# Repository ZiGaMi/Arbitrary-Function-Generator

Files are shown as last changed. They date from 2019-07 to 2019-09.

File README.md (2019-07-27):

# Arbitrary-Function-Generator
This repository contains of KiCad schematic and layout files, RTL code for iCE40 FPGA, C code for STM32F031K6 MCU and python script for software configuration of function generator.  

## Description
DAC: 12-bit R-2R ladder\
Output voltage: 3.3V\
SC current: 3.3mA

### Modes
Sinus: up to 1MHz\
Square: up to 100kHz\
Triange: up to 100kHz\
Saw: up to 100kHz\
Arbitrary: TBD

## Pics

3d_pic

work still in process...

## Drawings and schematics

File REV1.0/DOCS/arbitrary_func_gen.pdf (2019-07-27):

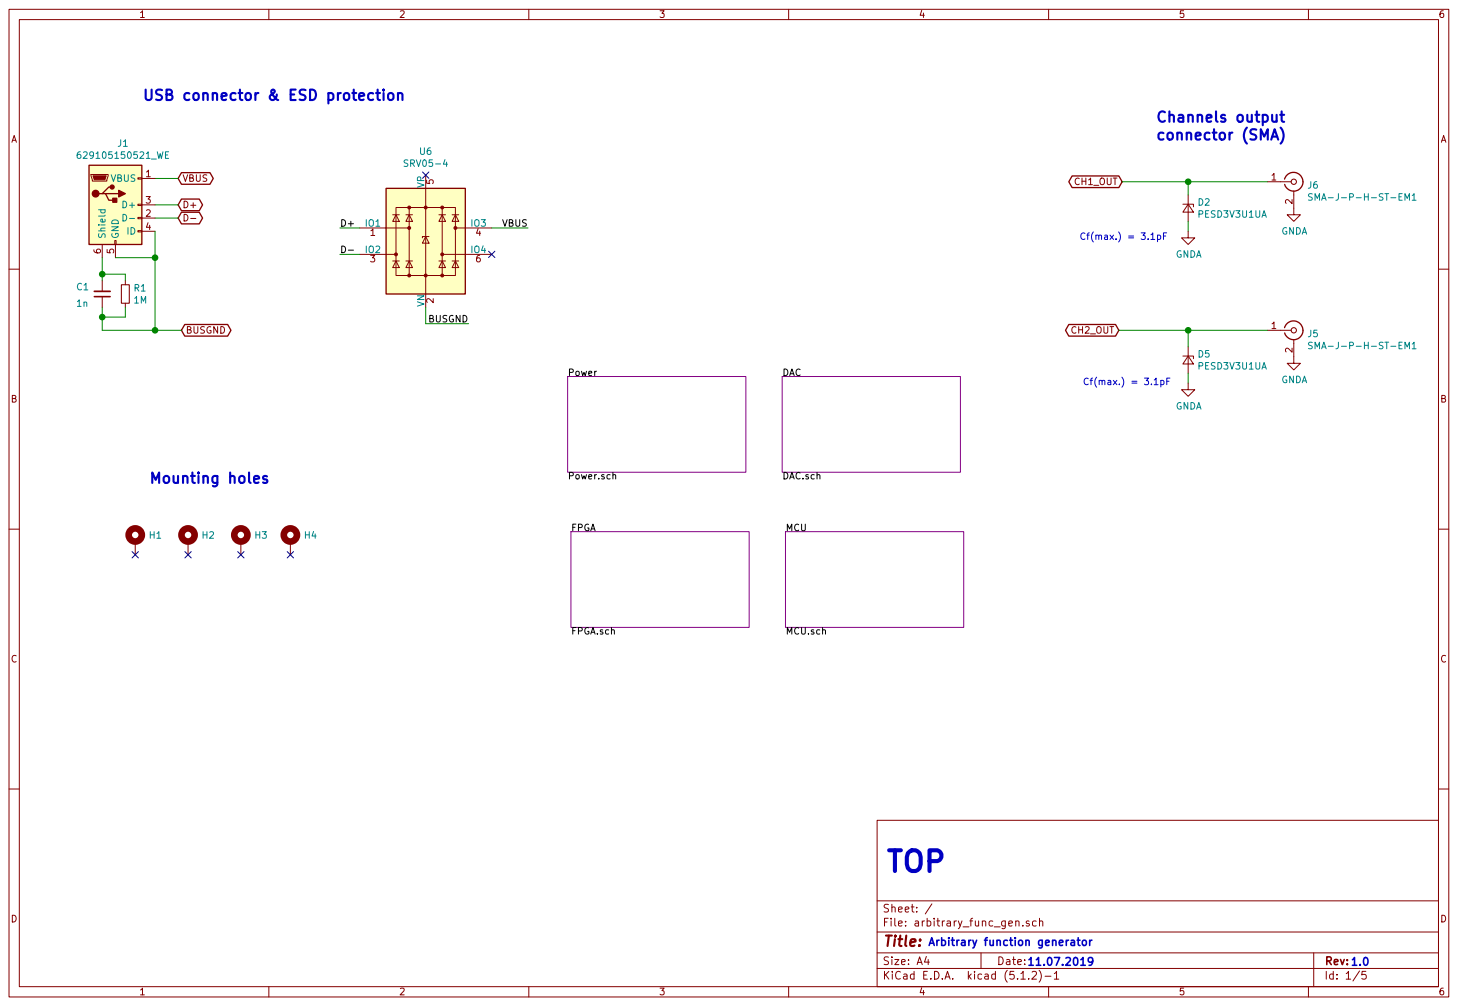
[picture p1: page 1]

J5 SMA-J-P-H-ST-EM1 GNDA D2PESD3V3U1UA GNDAD5PESD3V3U1UA GNDA Cf(max.) = 3.1pF

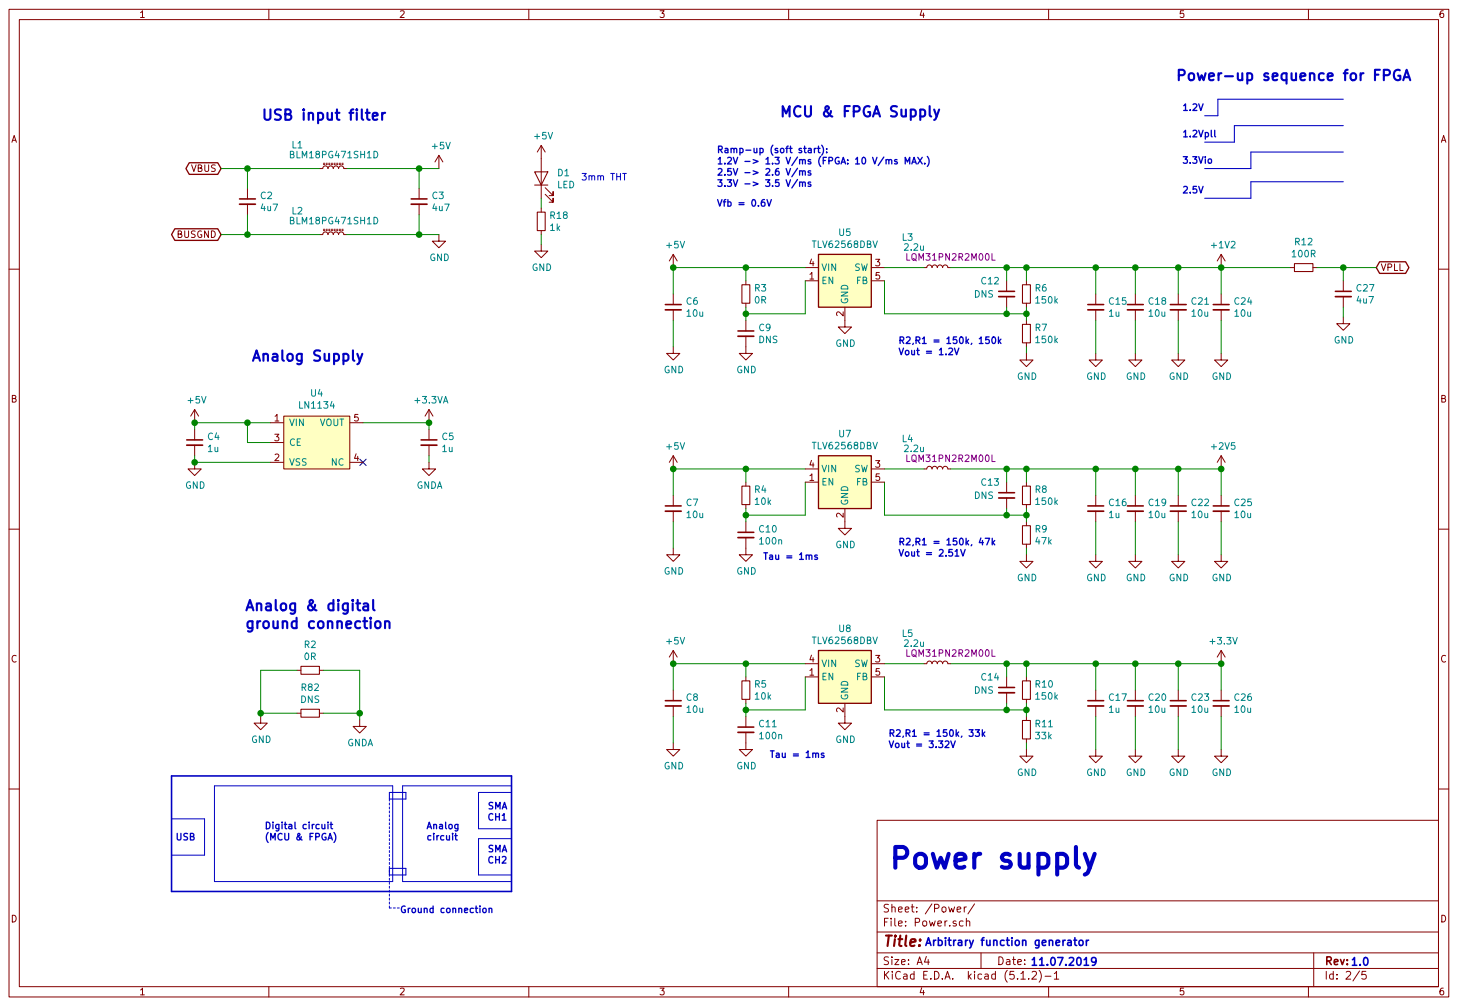
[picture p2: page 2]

Ramp-up (soft start):
1.2V -> 1.3 V/ms (FPGA: 10 V/ms MAX.) 2.5V -> 2.6 V/ms

Id: 2/5 Title: File: Power.sch Sheet: /Power/ Power supply

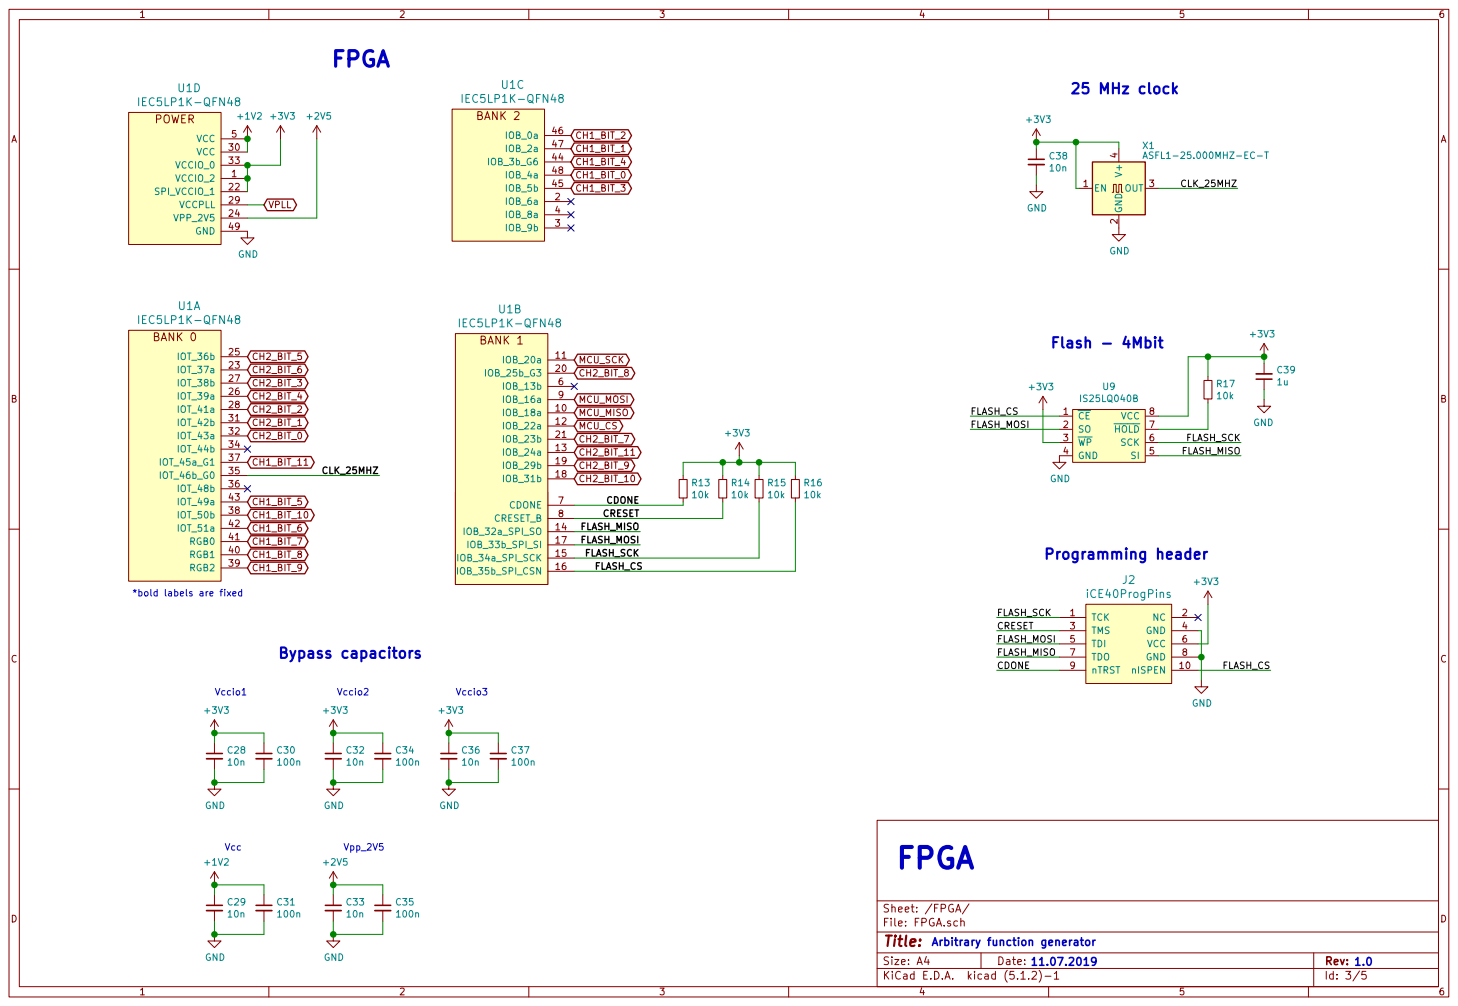
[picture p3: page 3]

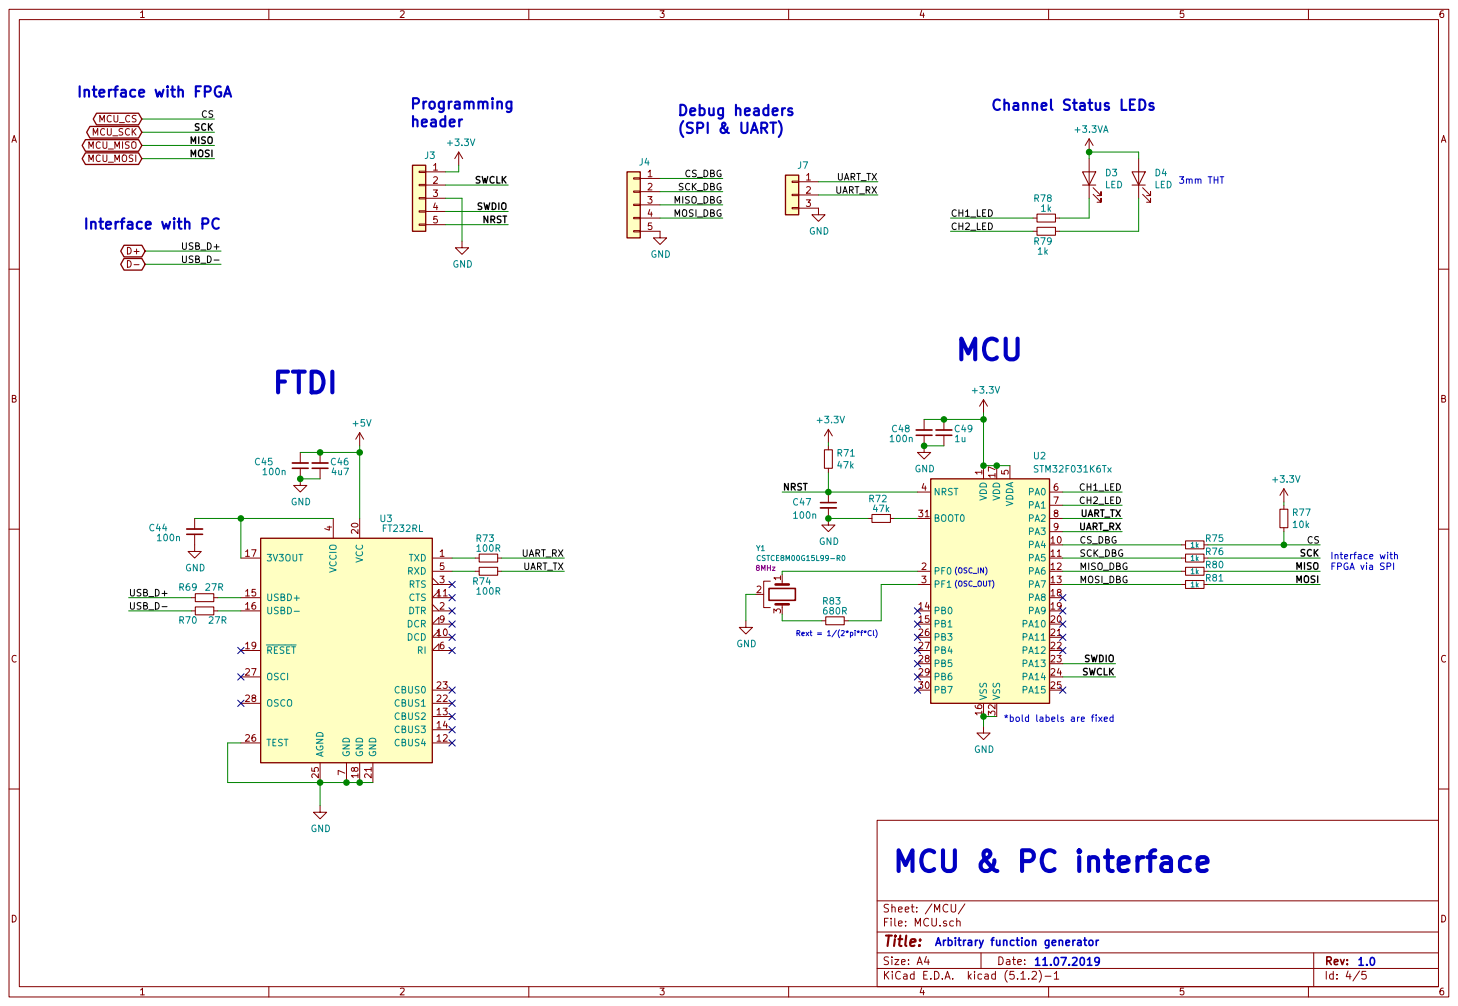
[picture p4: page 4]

SCK MISO MOSI CS MCU_SCK MCU_CS MCU_MISO MCU_MOSI Interface with FPGA

5 VSS 16 VSS 32 U2STM32F031K6Tx SCK MISO MOSI CS

Interface with FPGA via SPI

*bold labels are fixedSWDIO

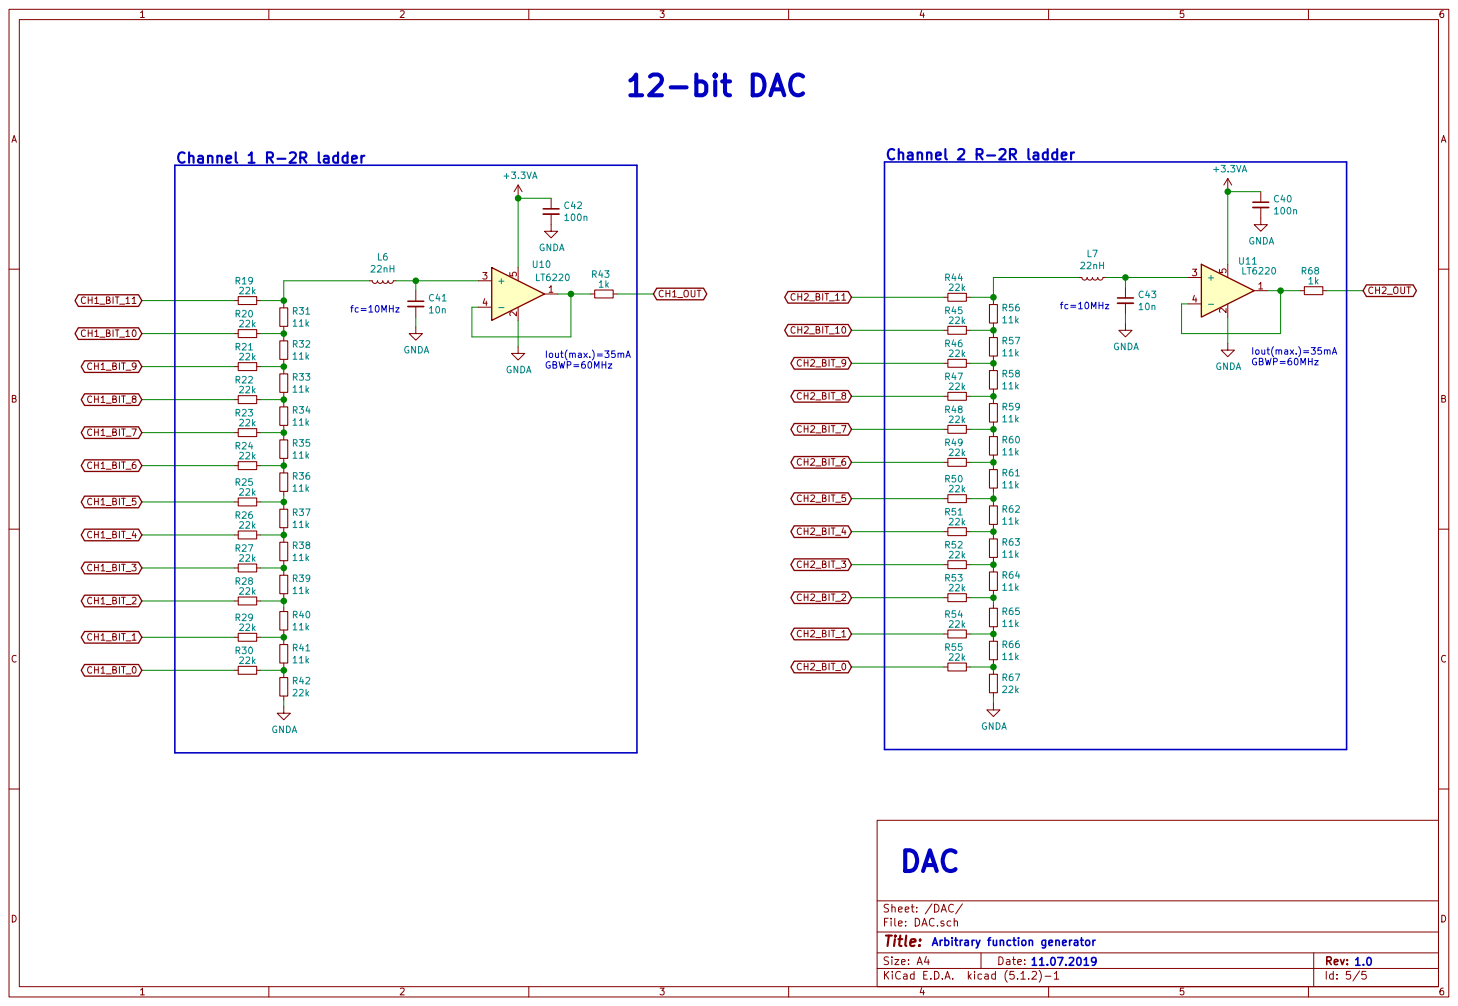
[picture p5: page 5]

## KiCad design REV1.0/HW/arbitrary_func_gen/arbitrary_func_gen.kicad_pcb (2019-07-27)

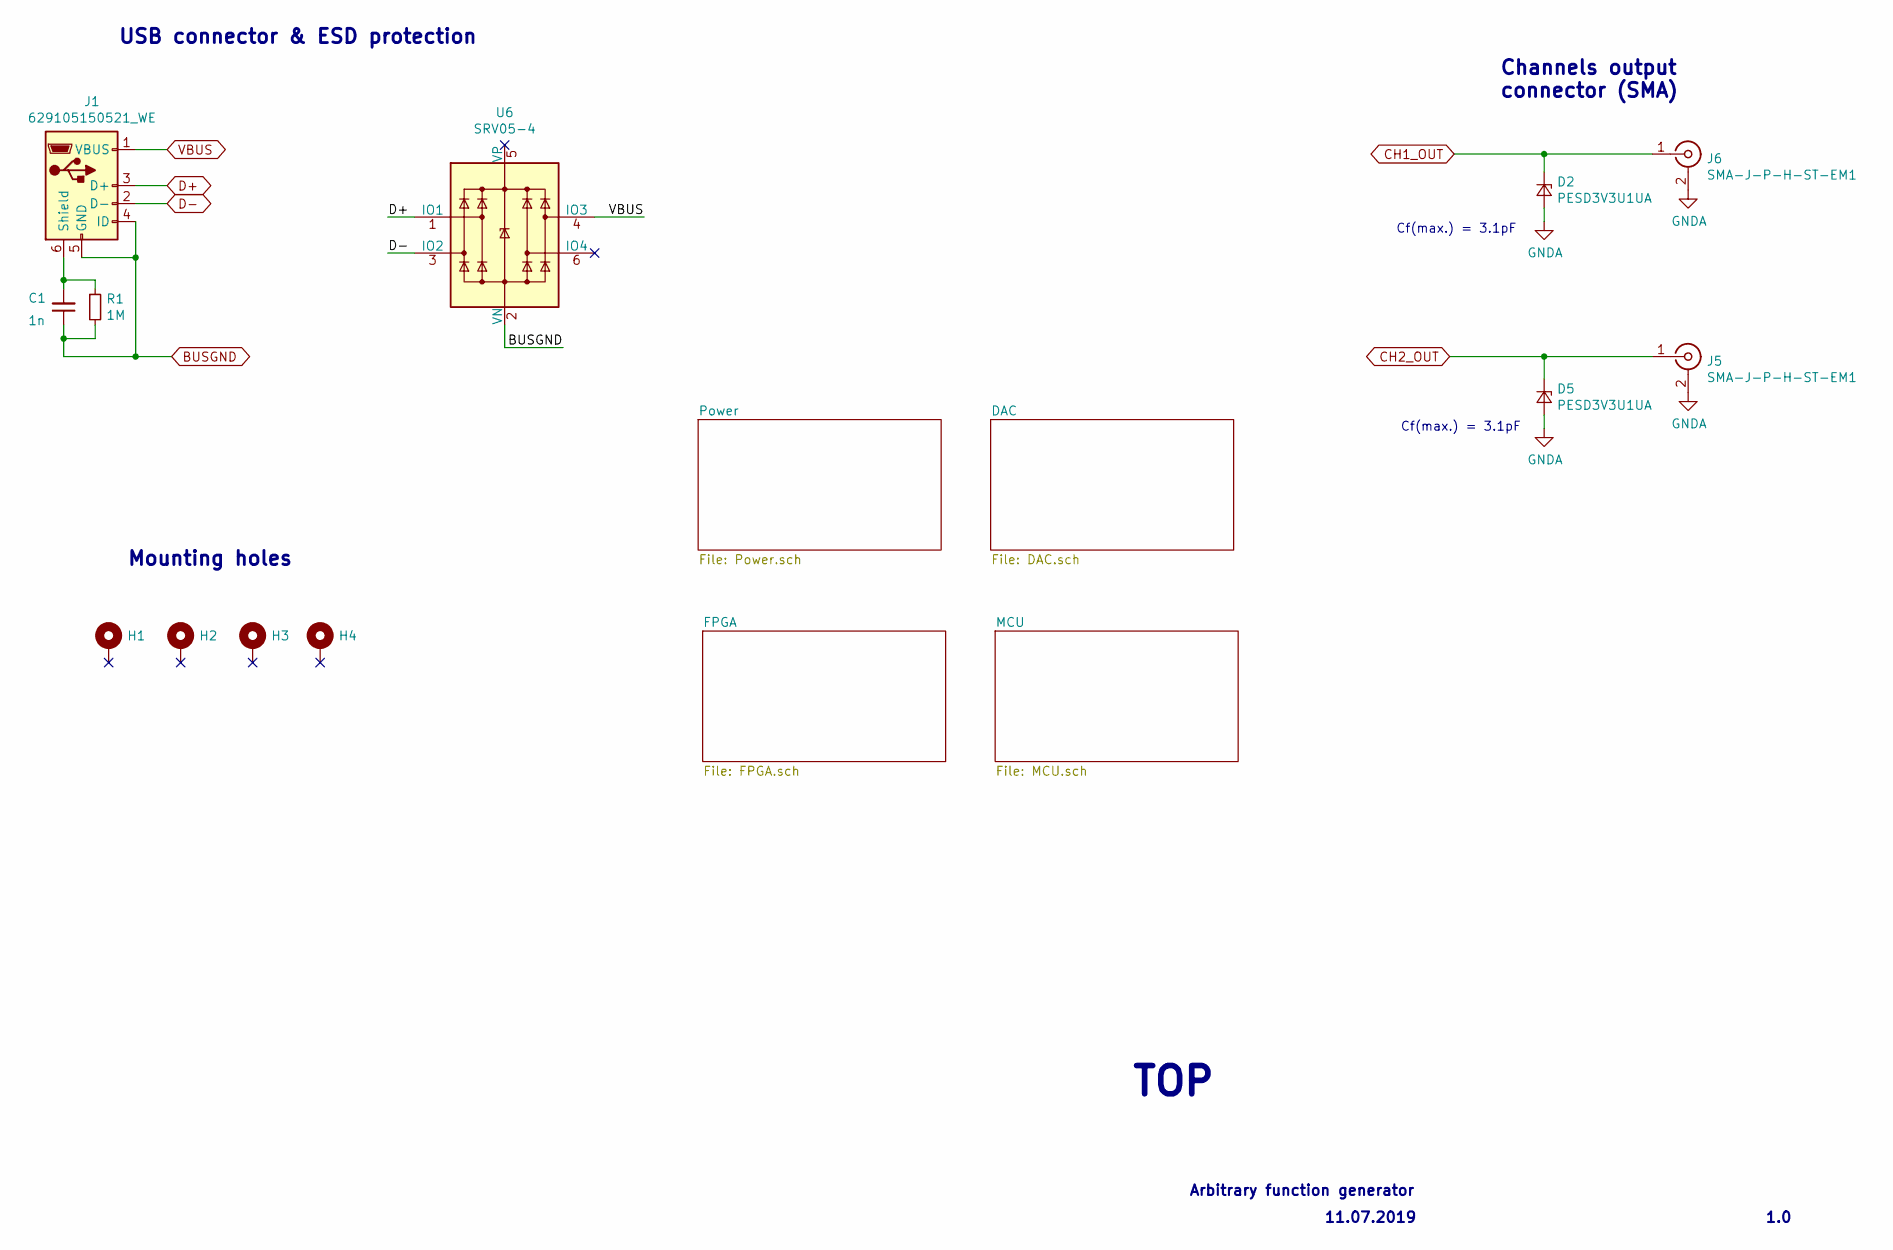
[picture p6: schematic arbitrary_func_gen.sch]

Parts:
C1: 1n; C_0603_HandSoldering
D2, D5: PESD3V3U1UA; D_SOD-323_HandSoldering
H1, H2, H3, H4: MountingHole_3.2mm_M3_Pad
J1: 629105150521_WE; USBMicro_629105150521_WE
J5, J6: SMA-J-P-H-ST-EM1; SMA_Coaxsial_EdgeBoard_Connector
R1: 1M; R_0603_HandSoldering
U6: SRV05-4; SOT-23-6_Handsoldering

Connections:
BUSGND: C1.1, J1.4 (ID), J1.5 (GND), R1.2, U6.2 (VN); also elsewhere on the board
CH1_OUT: D2.1 (K), J6.1 (In); also elsewhere on the board
CH2_OUT: D5.1 (K), J5.1 (In); also elsewhere on the board
D+: J1.3 (D+), U6.1 (IO1); also elsewhere on the board
D-: J1.2 (D-), U6.3 (IO2); also elsewhere on the board
GNDA: D2.2 (A), D5.2 (A), J5.2 (Ext), J6.2 (Ext); also elsewhere on the board
unnamed: C1.2, J1.6 (Shield), R1.1
VBUS: J1.1 (VBUS), U6.4 (IO3); also elsewhere on the board

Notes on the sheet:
TOP
11.07.2019
1.0
Arbitrary function generator
USB connector & ESD protection
Mounting holes
Channels output connector (SMA)
Cf(max.) = 3.1pF

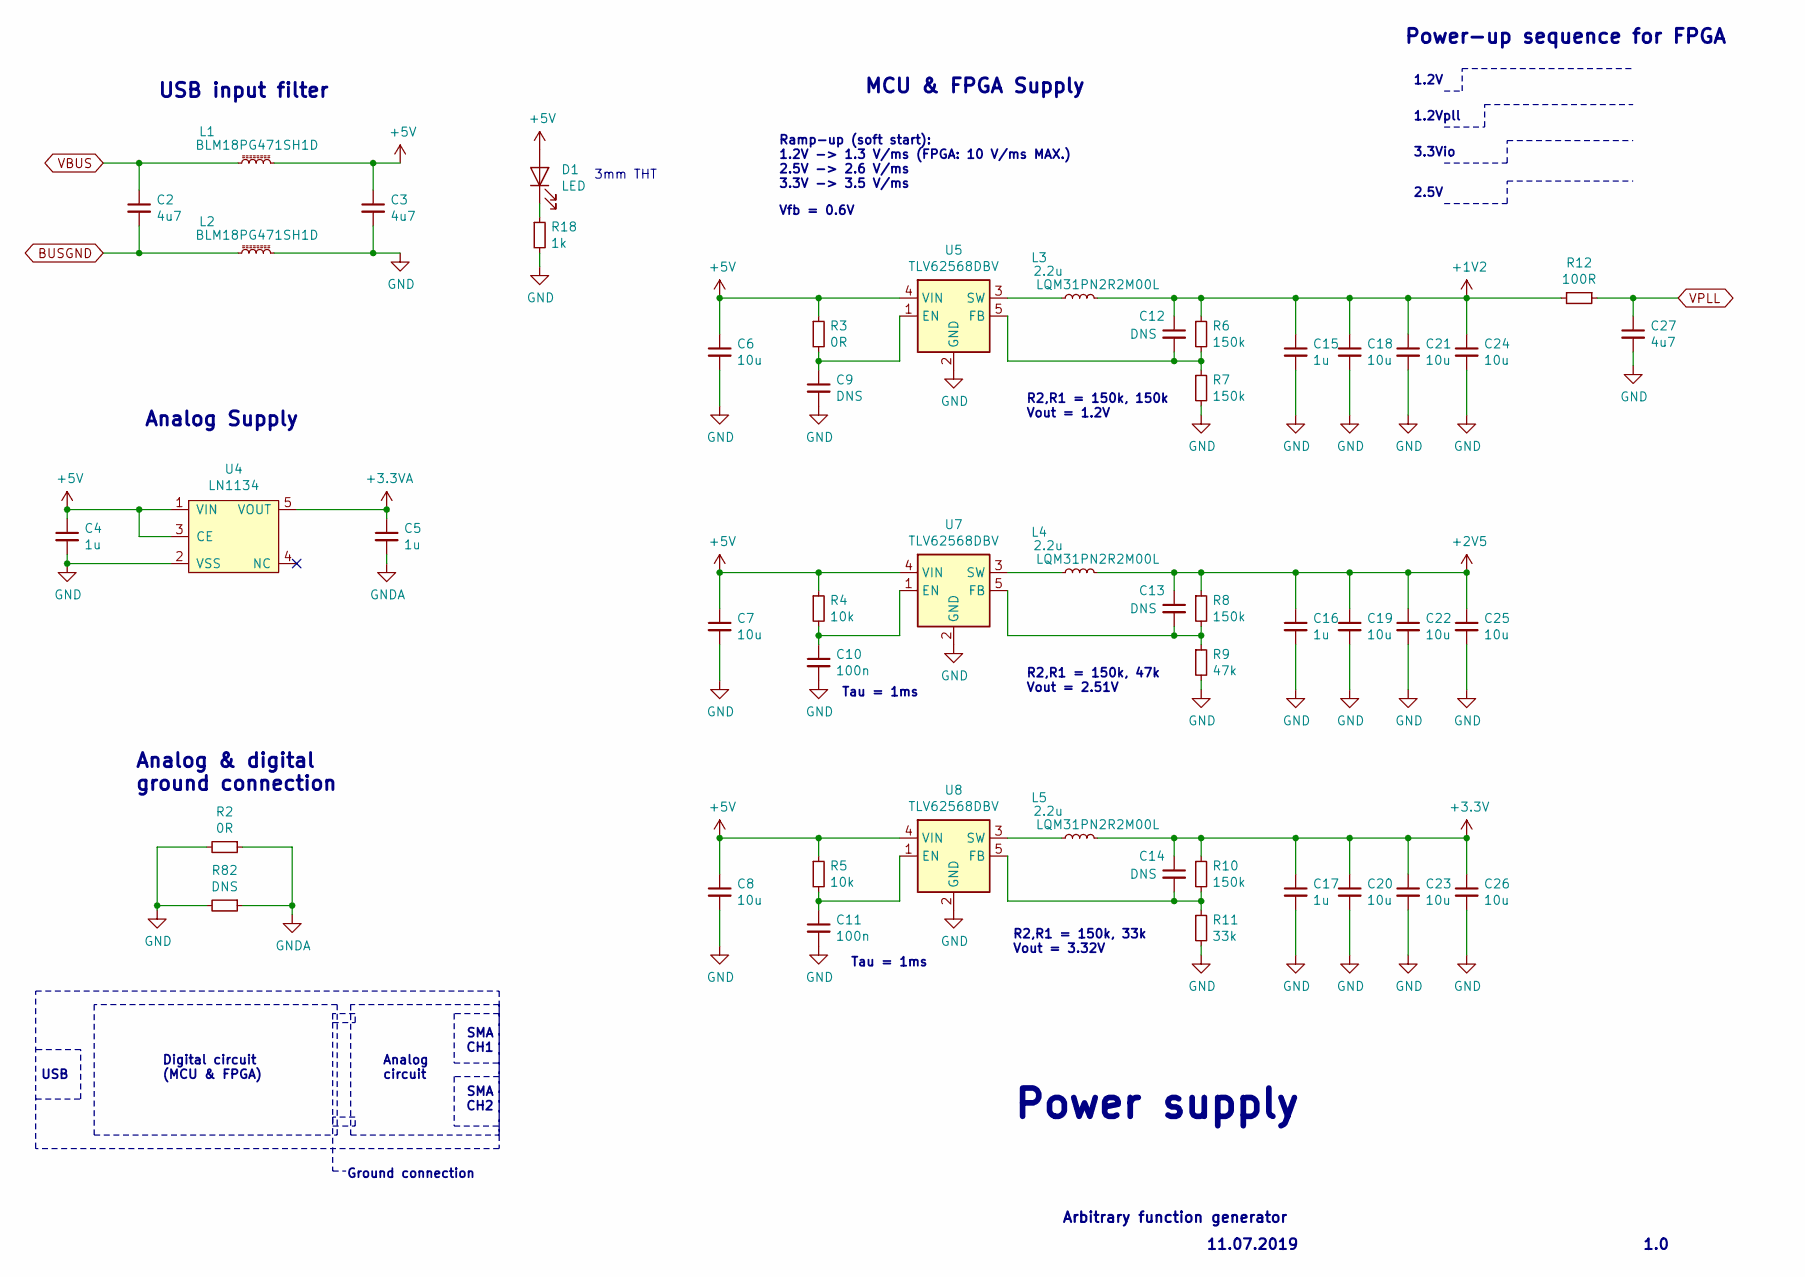
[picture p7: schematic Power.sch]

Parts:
C2, C3, C27: 4u7; C_0805_HandSoldering
C4, C5, C15, C16, C17: 1u; C_0603_HandSoldering
C6, C7, C8, C18, C19, C20, C21, C22, C23, C24, C25, C26: 10u; C_0805_HandSoldering
C9, C12, C13, C14: DNS; C_0603_HandSoldering
C10, C11: 100n; C_0603_HandSoldering
D1: LED; LED_D3.0mm_FlatTop
L1, L2: BLM18PG471SH1D; L_0603_HandSoldering
L3, L4, L5: 2.2u; L_1206_HandSoldering
R2: 0R; R_1206_HandSoldering
R3: 0R; R_0603_HandSoldering
R4, R5: 10k; R_0603_HandSoldering
R6, R7, R8, R10: 150k; R_0603_HandSoldering
R9: 47k; R_0603_HandSoldering
R11: 33k; R_0603_HandSoldering
R12: 100R; R_0603_HandSoldering
R18: 1k; R_0603_HandSoldering
R82: DNS; R_1206_HandSoldering
U4: LN1134; SOT-23-5_HandSoldering
U5, U7, U8: TLV62568DBV; SOT-23-5_HandSoldering

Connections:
+1V2: C12.1, C15.1, C18.1, C21.1, C24.1, L3.2, R6.1, R12.2; also elsewhere on the board
+2V5: C13.1, C16.1, C19.1, C22.1, C25.1, L4.2, R8.1; also elsewhere on the board
+3.3VA: C5.1, U4.5 (VOUT); also elsewhere on the board
+5V: C3.1, C4.1, C6.1, C7.1, C8.1, D1.2 (A), L1.2, R3.1, R4.1, R5.1, U4.1 (VIN), U4.3 (CE), U5.4 (VIN), U7.4 (VIN), U8.4 (VIN); also elsewhere on the board
BUSGND: C2.2, L2.1; also elsewhere on the board
GND: C3.2, C4.2, C6.2, C7.2, C8.2, C9.2, C10.2, C11.2, C15.2, C16.2, C17.2, C18.2, C19.2, C20.2, C21.2, C22.2, C23.2, C24.2, C25.2, C26.2, C27.2, L2.2, R2.2, R7.2, R9.2, R11.2, R18.2, R82.2, U4.2 (VSS), U5.2 (GND), U7.2 (GND), U8.2 (GND); also elsewhere on the board
GNDA: C5.2, R2.1, R82.1; also elsewhere on the board
unnamed: C9.1, R3.2, U5.1 (EN)
unnamed: C10.1, R4.2, U7.1 (EN)
unnamed: C11.1, R5.2, U8.1 (EN)
unnamed: C12.2, R6.2, R7.1, U5.5 (FB)
unnamed: C13.2, R8.2, R9.1, U7.5 (FB)
unnamed: C14.2, R10.2, R11.1, U8.5 (FB)
unnamed: D1.1 (K), R18.1
unnamed: L3.1, U5.3 (SW)
unnamed: L4.1, U7.3 (SW)
unnamed: L5.1, U8.3 (SW)
VBUS: C2.1, L1.1; also elsewhere on the board
VPLL: C27.1, R12.1; also elsewhere on the board

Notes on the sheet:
Power supply
Arbitrary function generator
11.07.2019
1.0
USB input filter
Power-up sequence for FPGA
1.2V
1.2Vpll
3.3Vio
2.5V
MCU & FPGA Supply
Analog Supply
Analog & digital ground connection
Analog circuit
Digital circuit (MCU & FPGA)
USB
SMA CH2
SMA CH1
Ground connection
Ramp-up (soft start): 1.2V -> 1.3 V/ms (FPGA: 10 V/ms MAX.) 2.5V -> 2.6 V/ms 3.3V -> 3.5 V/ms
Vfb = 0.6V
R2,R1 = 150k, 33k Vout = 3.32V
R2,R1 = 150k, 47k Vout = 2.51V
R2,R1 = 150k, 150k Vout = 1.2V
Tau = 1ms
3mm THT

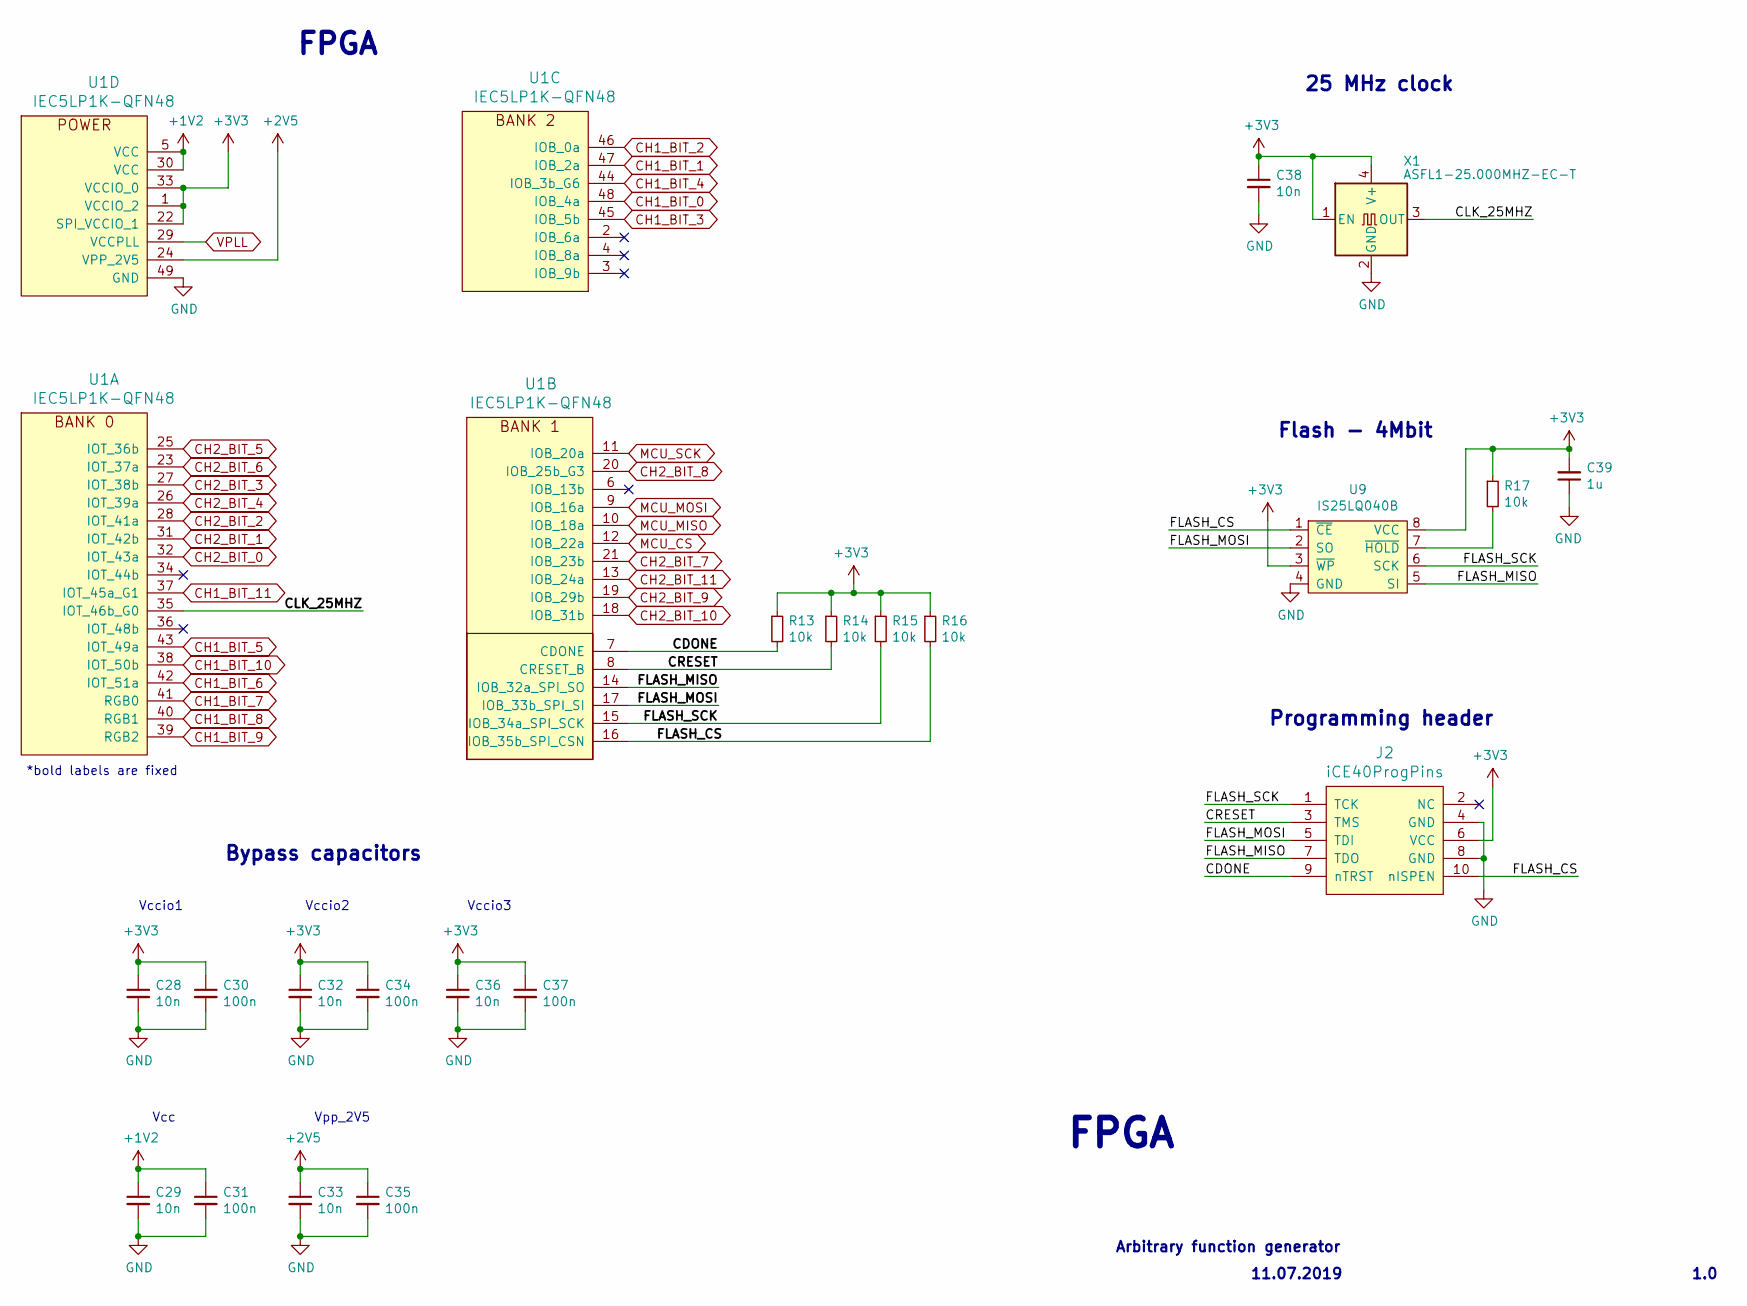
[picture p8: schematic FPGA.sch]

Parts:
C28, C29, C32, C33, C36, C38: 10n; C_0603_HandSoldering
C30, C31, C34, C35, C37: 100n; C_0603_HandSoldering
C39: 1u; C_0603_HandSoldering
J2: iCE40ProgPins; 2x5pin-R1.27mm
R13, R14, R15, R16, R17: 10k; R_0603_HandSoldering
U1: IEC5LP1K-QFN48; QFP-48_7x7_Pitch0.5mm
U9: IS25LQ040B; SOIC-8_3.9x4.9mm_Pitch1.27mm
X1: ASFL1-25.000MHZ-EC-T; Oscillator_SMD_Abracon_ASE-4pin_3.2x2.5mm_HandSoldering

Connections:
+1V2: C29.1, C31.1, U1.5 (VCC), U1.30 (VCC); also elsewhere on the board
+2V5: C33.1, C35.1, U1.24 (VPP_2V5); also elsewhere on the board
/FPGA/CDONE: J2.9 (nTRST), R13.2, U1.7 (CDONE)
/FPGA/CLK_25MHZ: U1.35 (IOT_46b_G0), X1.3 (OUT)
/FPGA/CRESET: J2.3 (TMS), R14.2, U1.8 (CRESET_B)
/FPGA/FLASH_CS: J2.10 (nISPEN), R16.2, U1.16 (IOB_35b_SPI_CSN), U9.1 (~CE)
/FPGA/FLASH_MISO: J2.7 (TDO), U1.14 (IOB_32a_SPI_SO), U9.5 (SI)
/FPGA/FLASH_MOSI: J2.5 (TDI), U1.17 (IOB_33b_SPI_SI), U9.2 (SO)
/FPGA/FLASH_SCK: J2.1 (TCK), R15.2, U1.15 (IOB_34a_SPI_SCK), U9.6 (SCK)
CH1_BIT_0: U1.48 (IOB_4a); also elsewhere on the board
CH1_BIT_1: U1.47 (IOB_2a); also elsewhere on the board
CH1_BIT_2: U1.46 (IOB_0a); also elsewhere on the board
CH1_BIT_3: U1.45 (IOB_5b); also elsewhere on the board
CH1_BIT_4: U1.44 (IOB_3b_G6); also elsewhere on the board
CH1_BIT_5: U1.43 (IOT_49a); also elsewhere on the board
CH1_BIT_6: U1.42 (IOT_51a); also elsewhere on the board
CH1_BIT_7: U1.41 (RGB0); also elsewhere on the board
CH1_BIT_8: U1.40 (RGB1); also elsewhere on the board
CH1_BIT_9: U1.39 (RGB2); also elsewhere on the board
CH1_BIT_10: U1.38 (IOT_50b); also elsewhere on the board
CH1_BIT_11: U1.37 (IOT_45a_G1); also elsewhere on the board
CH2_BIT_0: U1.32 (IOT_43a); also elsewhere on the board
CH2_BIT_1: U1.31 (IOT_42b); also elsewhere on the board
CH2_BIT_2: U1.28 (IOT_41a); also elsewhere on the board
CH2_BIT_3: U1.27 (IOT_38b); also elsewhere on the board
CH2_BIT_4: U1.26 (IOT_39a); also elsewhere on the board
CH2_BIT_5: U1.25 (IOT_36b); also elsewhere on the board
CH2_BIT_6: U1.23 (IOT_37a); also elsewhere on the board
CH2_BIT_7: U1.21 (IOB_23b); also elsewhere on the board
CH2_BIT_8: U1.20 (IOB_25b_G3); also elsewhere on the board
CH2_BIT_9: U1.19 (IOB_29b); also elsewhere on the board
CH2_BIT_10: U1.18 (IOB_31b); also elsewhere on the board
CH2_BIT_11: U1.13 (IOB_24a); also elsewhere on the board
GND: C28.2, C29.2, C30.2, C31.2, C32.2, C33.2, C34.2, C35.2, C36.2, C37.2, C38.2, C39.1, J2.4 (GND), J2.8 (GND), U1.49 (GND), U9.4 (GND), X1.2 (GND); also elsewhere on the board
MCU_CS: U1.12 (IOB_22a); also elsewhere on the board
MCU_MISO: U1.10 (IOB_18a); also elsewhere on the board
MCU_MOSI: U1.9 (IOB_16a); also elsewhere on the board
MCU_SCK: U1.11 (IOB_20a); also elsewhere on the board
unnamed: R17.2, U9.7 (~HOLD)
VPLL: U1.29 (VCCPLL); also elsewhere on the board

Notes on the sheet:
11.07.2019
1.0
Arbitrary function generator
FPGA
*bold labels are fixed
Vccio1
Vccio2
Vccio3
Vcc
Vpp_2V5
Bypass capacitors
25 MHz clock
Flash - 4Mbit
Programming header

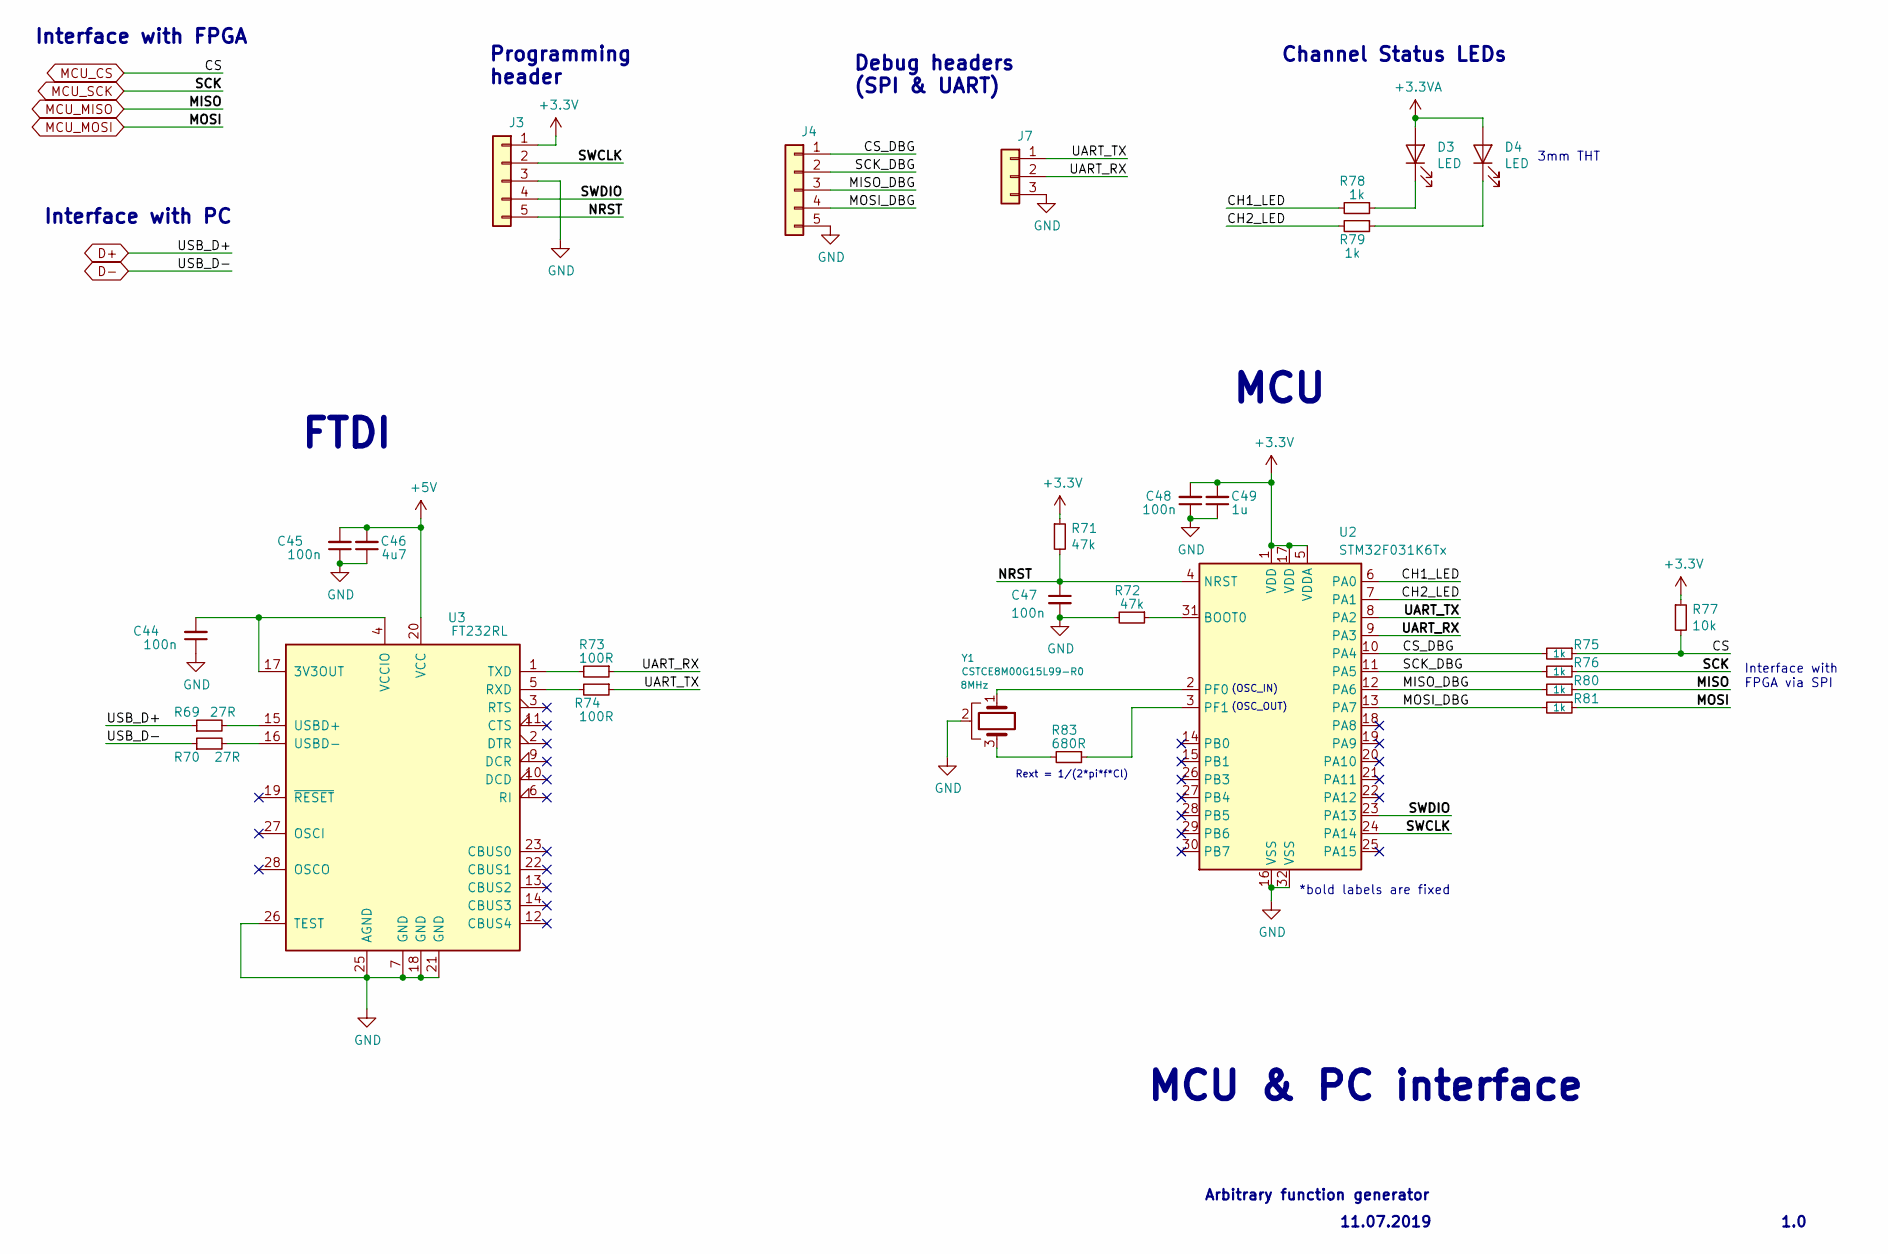
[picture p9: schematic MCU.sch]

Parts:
C44, C45, C47, C48: 100n; C_0603_HandSoldering
C46: 4u7; C_0805_HandSoldering
C49: 1u; C_0603_HandSoldering
D3, D4: LED; LED_D3.0mm_FlatTop
J3, J4: Conn_01x05; Pin_Header_Straight_1x05_Pitch2.54mm
J7: Conn_01x03; Pin_Header_Straight_1x03_Pitch2.54mm
R69, R70: 27R; R_0603_HandSoldering
R71, R72: 47k; R_0603_HandSoldering
R73, R74: 100R; R_0603_HandSoldering
R75, R76, R78, R79, R80, R81: 1k; R_0603_HandSoldering
R77: 10k; R_0603_HandSoldering
R83: 680R; R_0603_HandSoldering
U2: STM32F031K6Tx; LQFP-32_7x7mm_Pitch0.8mm
U3: FT232RL; SSOP-28_5.3x10.2mm_Pitch0.65mm
Y1: CSTCE8M00G15L99-R0; Crystal_Murata3Pin

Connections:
+3.3VA: D3.2 (A), D4.2 (A); also elsewhere on the board
+5V: C45.2, C46.2, U3.20 (VCC); also elsewhere on the board
/MCU/CH1_LED: R78.2, U2.6 (PA0)
/MCU/CH2_LED: R79.2, U2.7 (PA1)
/MCU/CS_DBG: J4.1, R75.2, U2.10 (PA4)
/MCU/MISO_DBG: J4.3, R80.2, U2.12 (PA6)
/MCU/MOSI_DBG: J4.4, R81.2, U2.13 (PA7)
/MCU/NRST: C47.1, J3.5, R71.2, U2.4 (NRST)
/MCU/SCK_DBG: J4.2, R76.2, U2.11 (PA5)
/MCU/SWCLK: J3.2, U2.24 (PA14)
/MCU/SWDIO: J3.4, U2.23 (PA13)
/MCU/UART_RX: J7.2, R73.1, U2.9 (PA3)
/MCU/UART_TX: J7.1, R74.1, U2.8 (PA2)
D+: R69.1; also elsewhere on the board
D-: R70.1; also elsewhere on the board
GND: C44.1, C45.1, C46.1, C47.2, C48.1, C49.1, J3.3, J4.5, J7.3, R72.2, U2.16 (VSS), U2.32 (VSS), U3.7 (GND), U3.18 (GND), U3.21 (GND), U3.25 (AGND), U3.26 (TEST), Y1.2; also elsewhere on the board
MCU_CS: R75.1, R77.2; also elsewhere on the board
MCU_MISO: R80.1; also elsewhere on the board
MCU_MOSI: R81.1; also elsewhere on the board
MCU_SCK: R76.1; also elsewhere on the board
unnamed: C44.2, U3.4 (VCCIO), U3.17 (3V3OUT)
unnamed: D3.1 (K), R78.1
unnamed: D4.1 (K), R79.1
unnamed: R69.2, U3.15 (USBD+)
unnamed: R70.2, U3.16 (USBD-)
unnamed: R72.1, U2.31 (BOOT0)
unnamed: R73.2, U3.1 (TXD)
unnamed: R74.2, U3.5 (RXD)
unnamed: R83.1, U2.3 (PF1)
unnamed: R83.2, Y1.3
unnamed: U2.2 (PF0), Y1.1

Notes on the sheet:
11.07.2019
1.0
Arbitrary function generator
MCU & PC interface
*bold labels are fixed
Programming header
Interface with FPGA via SPI
Interface with FPGA
Interface with PC
Debug headers (SPI & UART)
Channel Status LEDs
3mm THT
MCU
FTDI
(OSC_IN)
(OSC_OUT)
Rext = 1/(2*pi*f*Cl)

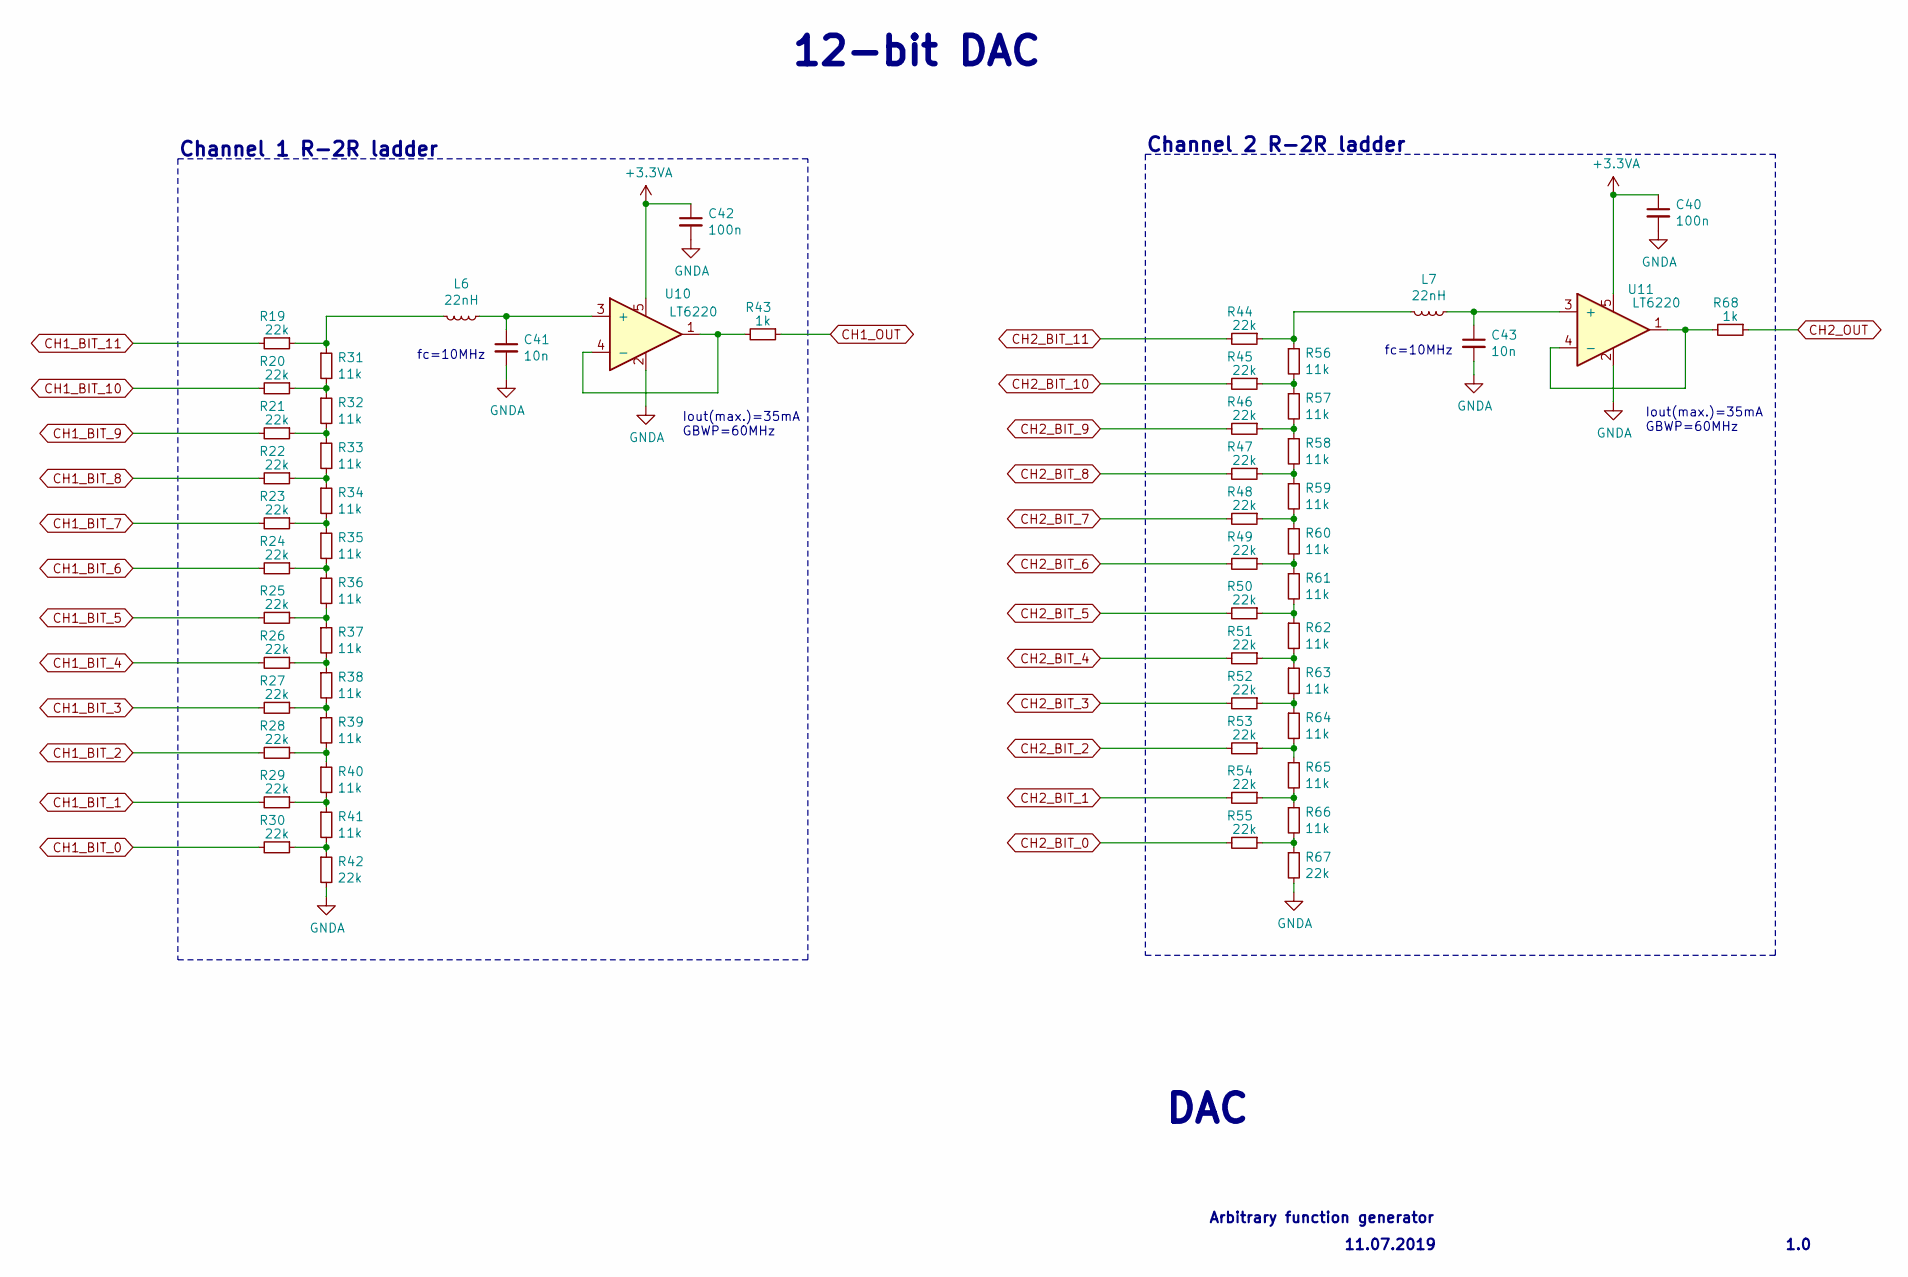
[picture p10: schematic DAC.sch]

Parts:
C40, C42: 100n; C_0603_HandSoldering
C41, C43: 10n; C_0603_HandSoldering
L6, L7: 22nH; L_0603_HandSoldering
R19, R20, R21, R22, R23, R24, R25, R26, R27, R28, R29, R30, R42, R44, R45, R46, R47, R48, R49, R50, R51, R52, R53, R54, R55, R67: 22k; R_0603_HandSoldering
R31, R32, R33, R34, R35, R36, R37, R38, R39, R40, R41, R56, R57, R58, R59, R60, R61, R62, R63, R64, R65, R66: 11k; R_0603_HandSoldering
R43, R68: 1k; R_0603_HandSoldering
U10, U11: LT6220; SOT-23-5_HandSoldering

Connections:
+3.3VA: C40.1, C42.1, U10.5, U11.5; also elsewhere on the board
CH1_BIT_0: R30.2; also elsewhere on the board
CH1_BIT_1: R29.2; also elsewhere on the board
CH1_BIT_2: R28.2; also elsewhere on the board
CH1_BIT_3: R27.2; also elsewhere on the board
CH1_BIT_4: R26.2; also elsewhere on the board
CH1_BIT_5: R25.2; also elsewhere on the board
CH1_BIT_6: R24.2; also elsewhere on the board
CH1_BIT_7: R23.2; also elsewhere on the board
CH1_BIT_8: R22.2; also elsewhere on the board
CH1_BIT_9: R21.2; also elsewhere on the board
CH1_BIT_10: R20.2; also elsewhere on the board
CH1_BIT_11: R19.2; also elsewhere on the board
CH1_OUT: R43.1; also elsewhere on the board
CH2_BIT_0: R55.2; also elsewhere on the board
CH2_BIT_1: R54.2; also elsewhere on the board
CH2_BIT_2: R53.2; also elsewhere on the board
CH2_BIT_3: R52.2; also elsewhere on the board
CH2_BIT_4: R51.2; also elsewhere on the board
CH2_BIT_5: R50.2; also elsewhere on the board
CH2_BIT_6: R49.2; also elsewhere on the board
CH2_BIT_7: R48.2; also elsewhere on the board
CH2_BIT_8: R47.2; also elsewhere on the board
CH2_BIT_9: R46.2; also elsewhere on the board
CH2_BIT_10: R45.2; also elsewhere on the board
CH2_BIT_11: R44.2; also elsewhere on the board
CH2_OUT: R68.1; also elsewhere on the board
GNDA: C40.2, C41.2, C42.2, C43.2, R42.2, R67.2, U10.2, U11.2; also elsewhere on the board
unnamed: C41.1, L6.1, U10.3 (+)
unnamed: C43.1, L7.1, U11.3 (+)
unnamed: L6.2, R19.1, R31.1
unnamed: L7.2, R44.1, R56.1
unnamed: R20.1, R31.2, R32.1
unnamed: R21.1, R32.2, R33.1
unnamed: R22.1, R33.2, R34.1
unnamed: R23.1, R34.2, R35.1
unnamed: R24.1, R35.2, R36.1
unnamed: R25.1, R36.2, R37.1
unnamed: R26.1, R37.2, R38.1
unnamed: R27.1, R38.2, R39.1
unnamed: R28.1, R39.2, R40.1
unnamed: R29.1, R40.2, R41.1
unnamed: R30.1, R41.2, R42.1
unnamed: R43.2, U10.1, U10.4 (-)
unnamed: R45.1, R56.2, R57.1
unnamed: R46.1, R57.2, R58.1
unnamed: R47.1, R58.2, R59.1
unnamed: R48.1, R59.2, R60.1
unnamed: R49.1, R60.2, R61.1
unnamed: R50.1, R61.2, R62.1
unnamed: R51.1, R62.2, R63.1
unnamed: R52.1, R63.2, R64.1
unnamed: R53.1, R64.2, R65.1
unnamed: R54.1, R65.2, R66.1
unnamed: R55.1, R66.2, R67.1
unnamed: R68.2, U11.1, U11.4 (-)

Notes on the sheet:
11.07.2019
1.0
Arbitrary function generator
DAC
fc=10MHz
Channel 1 R-2R ladder
Iout(max.)=35mA GBWP=60MHz
12-bit DAC
Channel 2 R-2R ladder

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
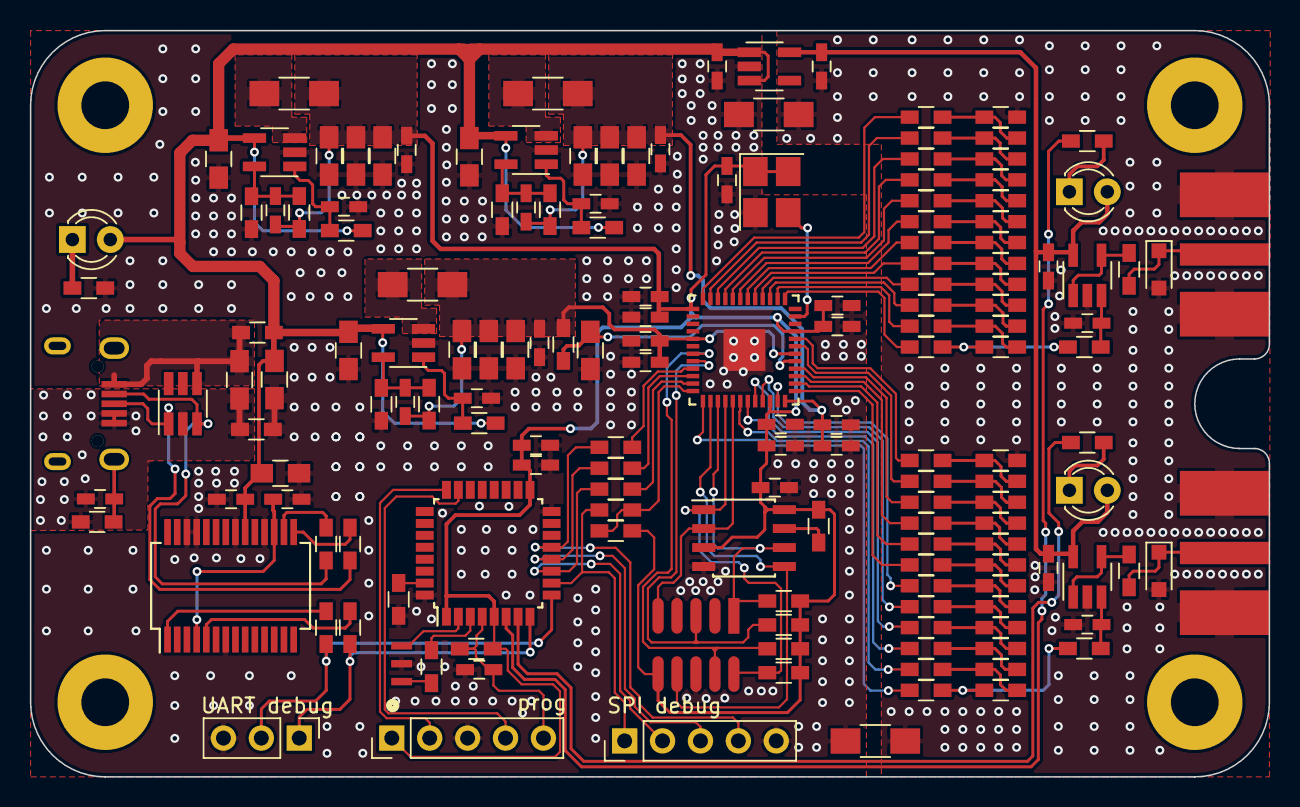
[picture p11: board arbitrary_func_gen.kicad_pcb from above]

Board: 2 copper layers, 83.0 x 50.0 mm, 168 parts (0 on the bottom side), 111 nets.

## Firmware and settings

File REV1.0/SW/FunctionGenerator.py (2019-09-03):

# # #
# # #		Function Generator 
# # #
# # #	Author:		Ziga M 
# # #	Date: 		27.07.2019
# # #

import os
import sys
import time
from FunctionGeneratorProtocol import ComPort
from FunctionGeneratorDefines import FunctionGeneratorDefines


Defines = FunctionGeneratorDefines()

# # # Intro 
def cliIntro(p, s):
	print("////////////////////////////////////////////////////////////////")
	print("//")
	print("//		Function Generator Rev1.0")
	print("//")
	print("//")
	print("//")
	print("//  COM port: %s (%s)" % ( p, s))
	print("//  FW version: 0.0")
	print("//  SoC version: 0.0")
	print("//")
	print("////////////////////////////////////////////////////////////////")
	print("")


if __name__ == "__main__":

	# Clear cmd
	os.system("cls")

	# Serial Port
	serPort = ComPort()
	port, ser_num = serPort.p_open()
	
	# CLI intro
	cliIntro(port, ser_num)
	
	
	while True:
		
		# Get command
		cmd = input("<FUNGEN>")
	
		# Apply command
		if cmd == Defines.CLI_QUIT_cmd:
			sys.exit()
			
		elif cmd == Defines.CLI_HELP_cmd:
			print("Help menu")
			
		elif cmd == Defines.CLI_INFO_cmd:
			print("Getting info...")
			
		elif cmd == Defines.CLI_CLEAR_cmd:
			os.system("cls")
			cliIntro(port, ser_num)
			
		elif cmd[:3] == "set":
			if cmd[4:8] == "sine":
				serPort.p_write([0xAA, 0x55, 0x05, Defines.WAVE_SINE_code, 0x00, 0x00, 0x10, ( 0x05 ^ Defines.WAVE_SINE_code ^ 0x10 )])
			elif cmd[4:8] == "sqrt":
				serPort.p_write([0xAA, 0x55, 0x05, Defines.WAVE_SQRT_code, 0x00, 0x00, 0x10, ( 0x05 ^ Defines.WAVE_SQRT_code ^ 0x10 )])
			elif cmd[4:8] == "rect":
				serPort.p_write([0xAA, 0x55, 0x05, Defines.WAVE_RECT_code, 0x00, 0x00, 0x10, ( 0x05 ^ Defines.WAVE_RECT_code ^ 0x10 )])
			elif cmd[4:7] == "saw":
				serPort.p_write([0xAA, 0x55, 0x05, Defines.WAVE_SAW_code, 0x00, 0x00, 0x10, ( 0x05 ^ Defines.WAVE_SAW_code ^ 0x10 )])
				
			#print("RX buffer: %s" % serPort.p_read(20))	
			print("Working buffer: %s" % serPort.p_read(20))	
			#print("Parsed data: %s" % serPort.p_read(20))	
			
		else:
			print("Unknown command... (enter >help< )")
	
	
	# Close port
	serPort.p_close()
	
	
	
	
	

	
	
	
	
	

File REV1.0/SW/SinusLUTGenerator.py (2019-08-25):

import os
import numpy as np
import matplotlib.pyplot as plt


# # # Number of elements in LUT
N = 50

# # # DAC resolution ( in bits )
DAC_RES = 10	



if __name__ == "__main__":
	
	n = 0.0
	sin_lut = []
	n_plt = []
	
	print ("uint16_t sin_lut[%s] = {" % N )
	
	for i in range(N):
	
		# # # Calculate sinus value
		sin_val = ( np.sin( n ) + 1 ) * (( 2**( DAC_RES - 1 ) - 1 )) + 500
		n += ( 2 * np.pi / N )
		
		# # # Verilog syntax 
		#print("sin_lut[%s] <= 12'd%i;" % ( i, sin_val ))
		print("%i," % sin_val)
		
		# # # Fill array
		sin_lut.append( sin_val )
		n_plt.append( n / ( 2 * np.pi ) )
		
	print("};")
		
		
	# # # Show wave
	plt.plot(n_plt, sin_lut, "-o")
	plt.grid()
	plt.show()

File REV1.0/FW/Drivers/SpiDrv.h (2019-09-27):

/*
 * SpiDrv.h
 *
 *  Created on: 3. sep. 2019
 *      Author: ZigaM
 */

#ifndef DRIVERS_SPIDRV_H_
#define DRIVERS_SPIDRV_H_

#include "stm32f0xx.h"

#include "Drivers/ClockDrv.h"


////////////////////////////////////////////////////////////////////////////////
//
//		Periphery
//
////////////////////////////////////////////////////////////////////////////////

// SPI
#define SPI							( SPI1 )

// SPI Tx DMA Channel
#define SPI_DMA_TX_CH				( DMA1_Channel2 )

// SPI Rx DMA Channel
#define SPI_DMA_RX_CH				( DMA1_Channel3 )




////////////////////////////////////////////////////////////////////////////////
//
//		Port / Pins defines
//
////////////////////////////////////////////////////////////////////////////////

#define SPI_port					( GPIOA )

#define SPI_CLK_bp					( 5u )
#define SPI_CLK_msk					( uint16_t ) ( 0x01u << SPI_CLK_bp )
#define SPI_CLK_afnum				( 0u )

#define SPI_MISO_bp					( 6u )
#define SPI_MISO_msk				( uint16_t ) ( 0x01u << SPI_MISO_bp )
#define SPI_MISO_afnum				( 0u )

#define SPI_MOSI_bp					( 7u )
#define SPI_MOSI_msk				( uint16_t ) ( 0x01u << SPI_MOSI_bp )
#define SPI_MOSI_afnum				( 0u )

#define SPI_CS_bp					( 4u )
#define SPI_CS_msk					( uint16_t ) ( 0x01u << SPI_CS_bp )




////////////////////////////////////////////////////////////////////////////////
//
//		SPI macros
//
////////////////////////////////////////////////////////////////////////////////

// Chip select
#define SPI_CS_high()				( SPI_port -> ODR |= ( SPI_CS_msk ))
#define SPI_CS_low()				( SPI_port -> ODR &= ~( SPI_CS_msk ))




////////////////////////////////////////////////////////////////////////////////
//
//	Check for reception buffer
//
////////////////////////////////////////////////////////////////////////////////

// Checking reception buffer time
#define SPI_CHECK_RX_BUFFER_TIME	( uint32_t ) ( 2000ul )		// ms




////////////////////////////////////////////////////////////////////////////////
//
//		Function prototypes
//
////////////////////////////////////////////////////////////////////////////////

// Init pins
void SpiPinsInit(void);

// Init dma
void SpiDmaInit(void);

// Init spi
void SpiInit(void);

// Send byte
uint8_t SpiSendByte(uint8_t);

// Send array
uint8_t * SpiSendArray(uint8_t*, uint8_t);

// Check timeout flag for rx buffer
uint8_t SpiGetRxBufferTimeoutFlag(void);




#endif /* DRIVERS_SPIDRV_H_ */

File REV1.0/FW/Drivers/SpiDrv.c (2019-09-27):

/*
 * SpiDrv.c
 *
 *  Created on: 3. sep. 2019
 *      Author: ZigaM
 */


#include "Drivers/SpiDrv.h"




// Init pins
void SpiPinsInit(){

	// Enable clock
	RCC -> AHBENR |= ( RCC_AHBENR_GPIOAEN );

	// Alternative functions
	SPI_port -> MODER &= ~(	(( 0x03u ) << ( 2ul * SPI_CLK_bp )) |
							(( 0x03u ) << ( 2ul * SPI_MISO_bp ))|
							(( 0x03u ) << ( 2ul * SPI_MOSI_bp ))|
							(( 0x03u ) << ( 2ul * SPI_CS_bp )));

	SPI_port -> MODER |=  (	(( 0x02u ) << ( 2ul * SPI_CLK_bp )) |
							(( 0x02u ) << ( 2ul * SPI_MISO_bp ))|
							(( 0x02u ) << ( 2ul * SPI_MOSI_bp )));


	// Alternative function number
#if ( SPI_CLK_bp > 7 )
	SPI_port -> AFR[1] &= ~( 0x0Fu << ( 4ul * ( SPI_CLK_bp - 8u )));
	SPI_port -> AFR[1] |= ( SPI_CLK_afnum << ( 4ul * ( SPI_CLK_bp - 8u )));
#else
	SPI_port -> AFR[0] &= ~( 0x0Fu << ( 4ul * SPI_CLK_bp ));
	SPI_port -> AFR[0] |= ( SPI_CLK_afnum << ( 4ul * SPI_CLK_bp ));
#endif

#if ( SPI_MOSI_bp > 7 )
	SPI_port -> AFR[1] &= ~( 0x0Fu << ( 4ul * ( SPI_MOSI_bp - 8u )));
	SPI_port -> AFR[1] |= ( SPI_MOSI_afnum << ( 4ul * ( SPI_MOSI_bp - 8u )));
#else
	SPI_port -> AFR[0] &= ~( 0x0Fu << ( 4ul * SPI_MOSI_bp ));
	SPI_port -> AFR[0] |= ( SPI_MOSI_afnum << ( 4ul * SPI_MOSI_bp ));
#endif

#if ( SPI_MISO_bp > 7 )
	SPI_port -> AFR[1] &= ~( 0x0Fu << ( 4ul * ( SPI_MISO_bp - 8u )));
	SPI_port -> AFR[1] |= ( SPI_MISO_afnum << ( 4ul * ( SPI_MISO_bp - 8u )));
#else
	SPI_port -> AFR[0] &= ~( 0x0Fu << ( 4ul * SPI_MISO_bp ));
	SPI_port -> AFR[0] |= ( SPI_MISO_afnum << ( 4ul * SPI_MISO_bp ));
#endif

	// CS standart output
	SPI_port -> MODER |= ( 0x01u << ( 2ul * SPI_CS_bp ));

	// CS high
	SPI_CS_high();
}


// Init dma
void SpiDmaInit(){


}


// Init spi
void SpiInit(){

	// Init pins
	SpiPinsInit();

	// Init dma
	//SpiDmaInit();

	// Enable SPI
	RCC -> APB2ENR |= ( RCC_APB2ENR_SPI1EN );

	// Disable SPI
	SPI -> CR1 = 0;

	// Fifo threahold
	// 8-bit data mode
	SPI -> CR2 = ( SPI_CR2_FRXTH | SPI_CR2_DS_0 | SPI_CR2_DS_1 | SPI_CR2_DS_2 | SPI_CR2_SSOE );

	// 1MHz baud
	// Enable SPI
	SPI -> CR1 = ( SPI_CR1_BR_1 | SPI_CR1_BR_0 | SPI_CR1_SPE | SPI_CR1_MSTR );
}



// Send byte
uint8_t SpiSendByte(uint8_t data){

	while(( SPI -> SR & SPI_SR_TXE ) != SPI_SR_TXE );
	*(uint8_t*) &( SPI -> DR ) = (uint8_t) ( data );

	while(( SPI -> SR & SPI_SR_RXNE ) != SPI_SR_RXNE );
	return (uint8_t) ( SPI -> DR );
}



// Send array
uint8_t *SpiSendArray(uint8_t *buf, uint8_t size){

	static uint8_t data[10];

	SPI_CS_low();
	for(uint8_t i = 0; i < size; i++){
		data[i] = SpiSendByte( buf[i] );
	}
	SPI_CS_high();
	return (uint8_t*) &( data );
}


// Check timeout flag for rx buffer
uint8_t SpiGetRxBufferTimeoutFlag(){

	static uint32_t now = 0ul;
	if ( (uint32_t) ( millis() - now ) >= SPI_CHECK_RX_BUFFER_TIME ){
		now = millis();
		return 1u;
	}
	else{
		return 0u;
	}
}

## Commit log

2019-07-11 new file: REV1.0/HW/arbitrary_func_gen/arbitrary_func_gen.kicad_pcb new file: REV1.0/HW/arbitrary_func_gen/arbitrary_func_gen.pro new file: REV1.0/HW/arbitrary_func_gen/arbitrary_func_gen.sch
    [arbitrary_func_gen.kicad_pcb, arbitrary_func_gen.sch]
2019-07-13 new file: HW/arbitrary_func_gen/DAC.bak new file: HW/arbitrary_func_gen/DAC.sch new file: HW/arbitrary_func_gen/FPGA.bak new file: HW/arbitrary_func_gen/FPGA.sch new file: HW/arbitrary_func_gen/MCU.b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
    [DAC.sch, FPGA.sch, MCU.sch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]
2019-07-13 modified: HW/arbitrary_func_gen/DAC.bak modified: HW/arbitrary_func_gen/DAC.sch modified: HW/arbitrary_func_gen/Power.bak modified: HW/arbitrary_func_gen/Power.sch modified: HW/arbitrary_func_gen/arb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
    [DAC.sch, Power.sch, arbitrary_func_gen.sch]
2019-07-13 modified: HW/arbitrary_func_gen/FPGA.bak modified: HW/arbitrary_func_gen/FPGA.sch modified: HW/arbitrary_func_gen/Power.bak modified: HW/arbitrary_func_gen/Power.sch modified: HW/arbitrary_func_gen/a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
    [FPGA.sch, Power.sch, arbitrary_func_gen.sch]
2019-07-20 modified: REV1.0/HW/arbitrary_func_gen/FPGA.bak modified: REV1.0/HW/arbitrary_func_gen/FPGA.sch modified: REV1.0/HW/arbitrary_func_gen/arbitrary_func_gen.bak modified: REV1.0/HW/arbitrary_func_gen/ar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
    [FPGA.sch, arbitrary_func_gen.sch]
2019-07-20 modified: DAC.bak modified: DAC.sch modified: FPGA.bak modified: FPGA.sch modified: MCU.bak modified: MCU.sch modified: Power.bak modified: Power.sch modified: arbitrary_func_gen-cache.lib
    [DAC.sch, FPGA.sch, MCU.sch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]
2019-07-20 modified: HW/arbitrary_func_gen/MCU.bak modified: HW/arbitrary_func_gen/MCU.sch
    [MCU.sch]
2019-07-20 modified: HW/arbitrary_func_gen/DAC.bak modified: HW/arbitrary_func_gen/DAC.sch modified: HW/arbitrary_func_gen/FPGA.bak modified: HW/arbitrary_func_gen/FPGA.sch modified: HW/arbitrary_func_gen/MCU.b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
    [DAC.sch, FPGA.sch, MCU.sch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]
2019-07-23 modified: ../DAC.bak modified: ../DAC.sch modified: ../FPGA.bak modified: ../FPGA.sch new file: arbitrary_func_gen-F_Cu.pdf modified: ../MCU.bak modified: ../MCU.sch modified: ../Power.bak modified: 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
    [DAC.sch, FPGA.sch, MCU.sch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]
2019-07-24 modified: REV1.0/HW/arbitrary_func_gen/arbitrary_func_gen-cache.lib modified: REV1.0/HW/arbitrary_func_gen/arbitrary_func_gen.bak modified: REV1.0/HW/arbitrary_func_gen/arbitrary_func_gen.kicad_pcb n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
    [arbitrary_func_gen.sch]
2019-07-24 modified: DAC.bak modified: DAC.sch modified: FPGA.bak modified: FPGA.sch modified: MCU.bak modified: MCU.sch modified: Power.bak modified: Power.sch modified: arbitrary_func_gen-cache.lib modified: 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
    [DAC.sch, FPGA.sch, MCU.sch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]
2019-07-24 modified: Power.sch new file: _autosave-Power.sch modified: arbitrary_func_gen.kicad_pcb modified: arbitrary_func_gen.kicad_pcb-bak modified: arbitrary_func_gen.net modified: fp-info-cache
    [arbitrary_func_gen.kicad_pcb]
2019-07-24 modified: arbitrary_func_gen/MCU.sch modified: arbitrary_func_gen/Power.bak deleted: arbitrary_func_gen/_autosave-Power.sch modified: arbitrary_func_gen/arbitrary_func_gen.kicad_pcb modified: arbitra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
    [MCU.sch, arbitrary_func_gen.kicad_pcb]
2019-07-25 new file: DOCS/arbitrary_func_gen.pdf modified: HW/arbitrary_func_gen/DAC.bak modified: HW/arbitrary_func_gen/DAC.sch modified: HW/arbitrary_func_gen/FPGA.bak modified: HW/arbitrary_func_gen/FPGA.sch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
    [DAC.sch, FPGA.sch, Power.sch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]
2019-07-25 modified: HW/arbitrary_func_gen/FPGA.bak modified: HW/arbitrary_func_gen/FPGA.sch modified: HW/arbitrary_func_gen/MCU.bak modified: HW/arbitrary_func_gen/MCU.sch modified: HW/arbitrary_func_gen/Power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
    [FPGA.sch, MCU.sch, Power.sch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]
2019-07-26 modified: FPGA.bak modified: MCU.bak modified: MCU.sch modified: arbitrary_func_gen.kicad_pcb modified: arbitrary_func_gen.kicad_pcb-bak modified: arbitrary_func_gen.net modified: arbitrary_func_gen.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
    [MCU.sch, arbitrary_func_gen.kicad_pcb]
2019-07-26 modified: MCU.bak modified: MCU.sch modified: arbitrary_func_gen-cache.lib modified: arbitrary_func_gen.kicad_pcb modified: arbitrary_func_gen.kicad_pcb-bak modified: arbitrary_func_gen.net modified: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
    [MCU.sch, arbitrary_func_gen.kicad_pcb]
2019-07-27 modified: HW/arbitrary_func_gen/Power.bak modified: HW/arbitrary_func_gen/Power.sch modified: HW/arbitrary_func_gen/arbitrary_func_gen.kicad_pcb modified: HW/arbitrary_func_gen/arbitrary_func_gen.kic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
    [Power.sch, arbitrary_func_gen.kicad_pcb]
2019-07-27 deleted: REV1.0/HW/arbitrary_func_gen/Gerbers/arbitrary_func_gen-F_Cu.pdf modified: REV1.0/HW/arbitrary_func_gen/arbitrary_func_gen.kicad_pcb modified: REV1.0/HW/arbitrary_func_gen/arbitrary_func_gen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
    [arbitrary_func_gen.kicad_pcb]
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2019-07-27 deleted: ../DOCS/3d_pic.png deleted: ../HW/arbitrary_func_gen/Gerbers/arbitrary_fun_gen_rev1.0_gerbers.zip deleted: ../HW/arbitrary_func_gen/Gerbers/arbitrary_func_gen-B_Cu.gbr deleted: ../HW/arbitra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
    [arbitrary_func_gen-B_Cu.gbr, arbitrary_func_gen-B_Mask.gbr, arbitrary_func_gen-B_SilkS.gbr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]
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
